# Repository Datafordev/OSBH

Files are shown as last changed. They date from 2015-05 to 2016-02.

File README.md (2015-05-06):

#Open Source Beehives Project #
#Alpha Sensor Kit #
====================================================

Developed for Open Source Beehives Project
http://opensourcebeehives.net

The master branch for the firmware is being rewritten.
The old Code is saved to the Alpha_Kit_02 branch.

**License**
--------
This application contains several libraries and files.  Check the comments section of the .cpp and .h files for the specific details on the licenses.

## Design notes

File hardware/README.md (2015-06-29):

#Open Source Beehives Project #
#Alpha Sensor Kit #
====================================================

Developed for Open Source Beehives Project
http://opensourcebeehives.net

**Hardware AlphaKit V.04**

We designed a shield for the Particle Core/Photon where you can attach following sensors:

- 2x Temp DS18B20
- 2x Temp and Humidity DHT22
- 2x Audio sensor (like audio breakout from SparkFun - more details in audio_sensor)
- 1x Weight sensor

There's also an micro SD Card Slot and a RTC Clock Device installed to be able to work in offline areas.

You'll find a Bill of materials list in bom.ods

**Important for producing the PCB**
It's a doublesided PCB so you need to make sure that pins and vias are through contacted!

**License**
--------
GPL

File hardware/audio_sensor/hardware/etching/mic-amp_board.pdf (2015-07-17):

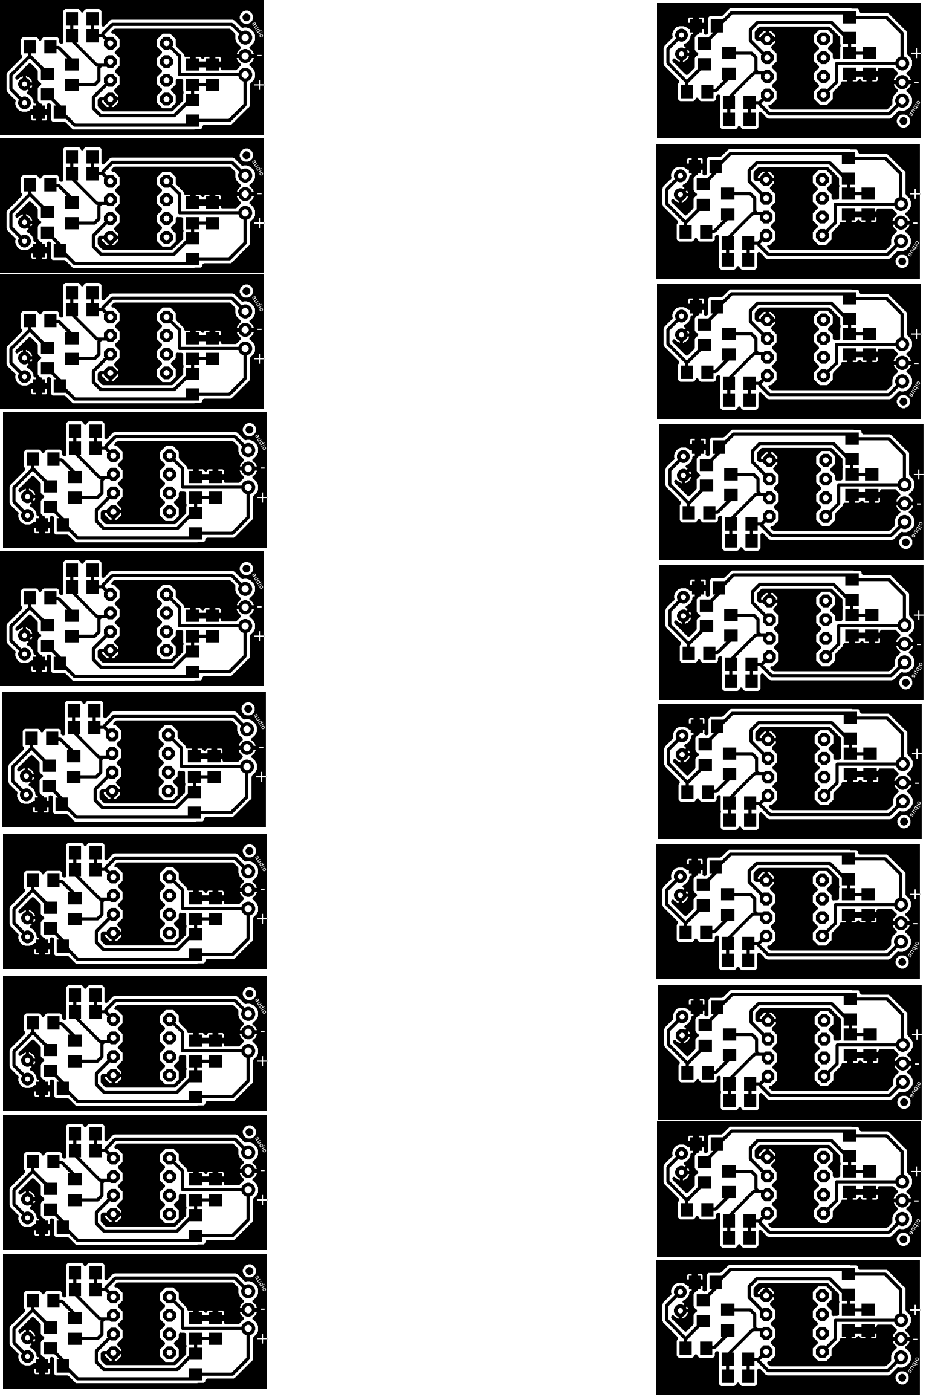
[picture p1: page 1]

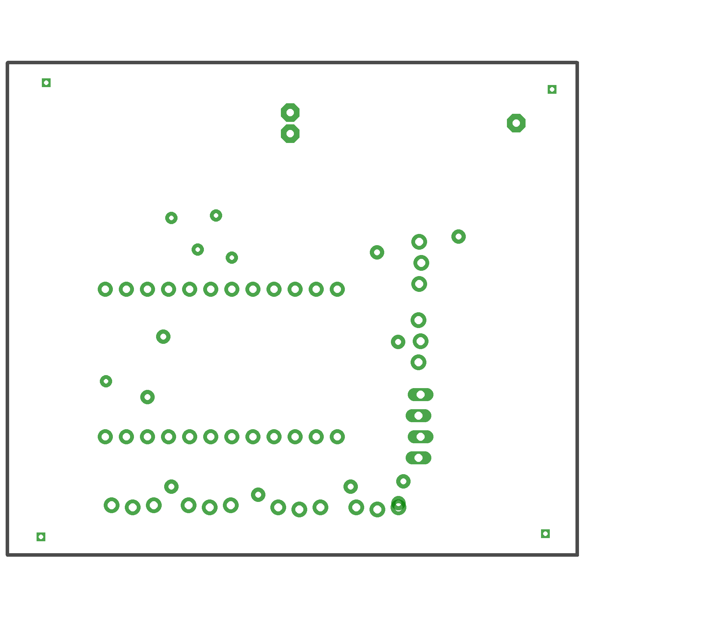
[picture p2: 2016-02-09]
hardware/etching/dimension.png

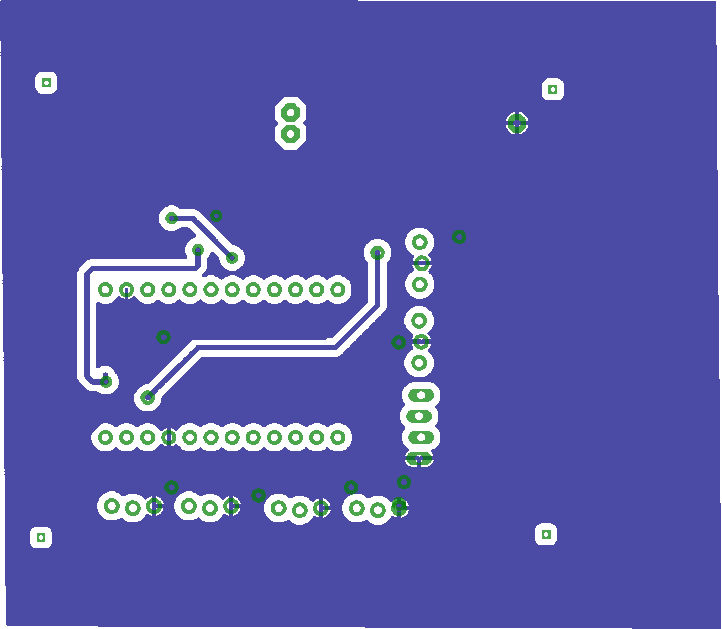
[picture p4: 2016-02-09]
hardware/etching/bottom.png

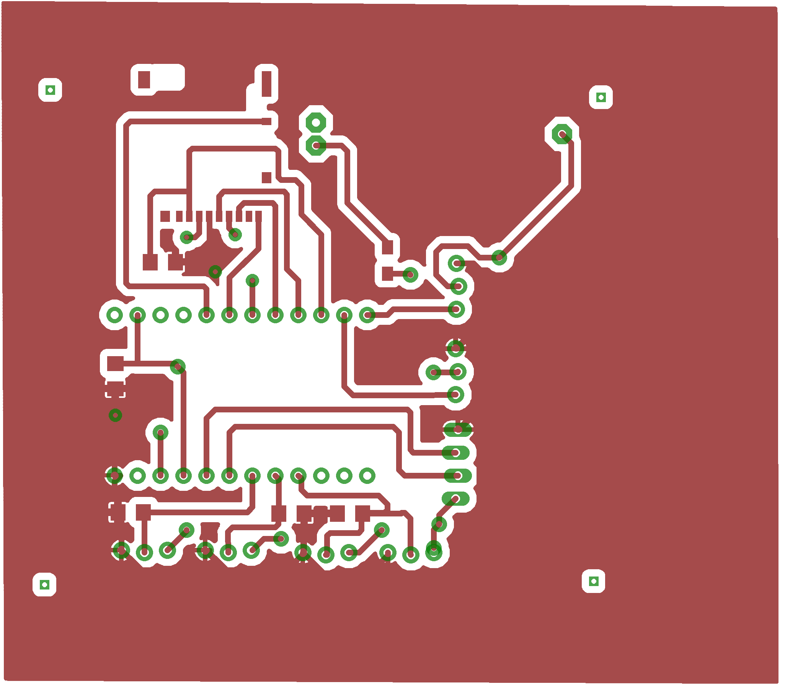
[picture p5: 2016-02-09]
hardware/etching/top.png

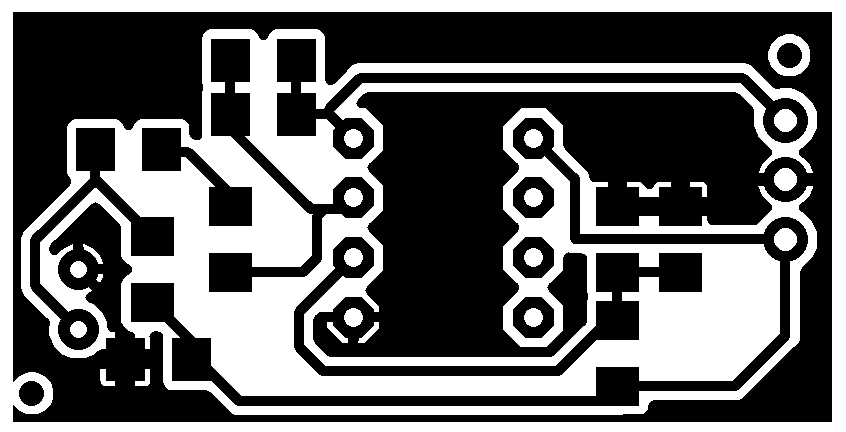
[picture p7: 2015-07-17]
hardware/audio_sensor/hardware/etching/mic-amp_board.png

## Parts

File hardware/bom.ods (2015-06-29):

ID | Type | Designator PCB | Description | Qty
Base Board
1 | Resistor | R5,R6,R7 | 0 Ohm Resistor SMD 1206 | 3
2 | Resistor | R4 | 10kOhm SMD 1206 | 1
3 | Resistor | R1,R2 | 1kOhm SMD 1206 | 2
4 | Resistor | R3 | 4,7kOhm SMD 1206 | 1
5 | Capacitor | C1 | 0.1uF Cap SMD 1206 (not sure yet) | 1
6 | SD Slot | MICROSD-HIROSE | DM3AT-SF-PEJM5 | 1
7 | Male Pins | Audio,Audio1,ADC,DHT03,DHT03_ext,DS18B20,DS18B20ext, | Male pin headers 6x3 + 4 Pin Spacing: 0.1" | 22
8 | Female Pins | JP1,JP2 | Female Headers 2x12 Pin Spacing: 0.1" | 24
9 | Spark Core |  |  | 1
10 | Battery Holder | HU-2032-LF
11 | Real Time Clock | ds1340
 |  |  |  |  | 30,00
Audio Board
10 | Microphone | M1 | MIC-9.7MM Sparkfun | 1
11 | Op-Amp | LM358 or similar | LM358 Op-Amp | 1
12 | Resistor | R1 | 2,2 Kohm Resistor | 1
13 | Capacitor | C1 | 22uF Capacitor SMD 1206 | 1
14 | Resistor | R2,R3,R4 | 10kOhm SMD 1206 | 3
15 | Capacitor | C2 | 1uF Capacitor SMD 1206 | 1
16 | Capacitor | C3 | 100pF Capacitor SMD 1206 | 1
17 | Capacitor | C4 | 0.1uF Cap SMD 1206 | 1
18 | Resistor | R5 | 1MOhm Resistor 1206 | 1
 |  |  |  |  | 5,00
Sensors
19 | Temp-Sensor |  | DS18B20 | 2 | 5
20 | HUMSensor |  | DHT22 Sensor | 2 | 8,00
21 | Weight |  | H30A Bosche Load Cell | 1 | 40
22 | ADC |  | Hx711 AD-Converter | 1 | 3
Connections
22 | Cables 3 wire |  | Cables 3 wires: Audio + 2x Hum (+Temp) ~ 50cm | 3 | 1
23 | Cables 4 wire |  | Cables 4 wire: ADC to Base Board | 1 | 0,5
Scales Construction
???
 |  |  |  |  | 92,5

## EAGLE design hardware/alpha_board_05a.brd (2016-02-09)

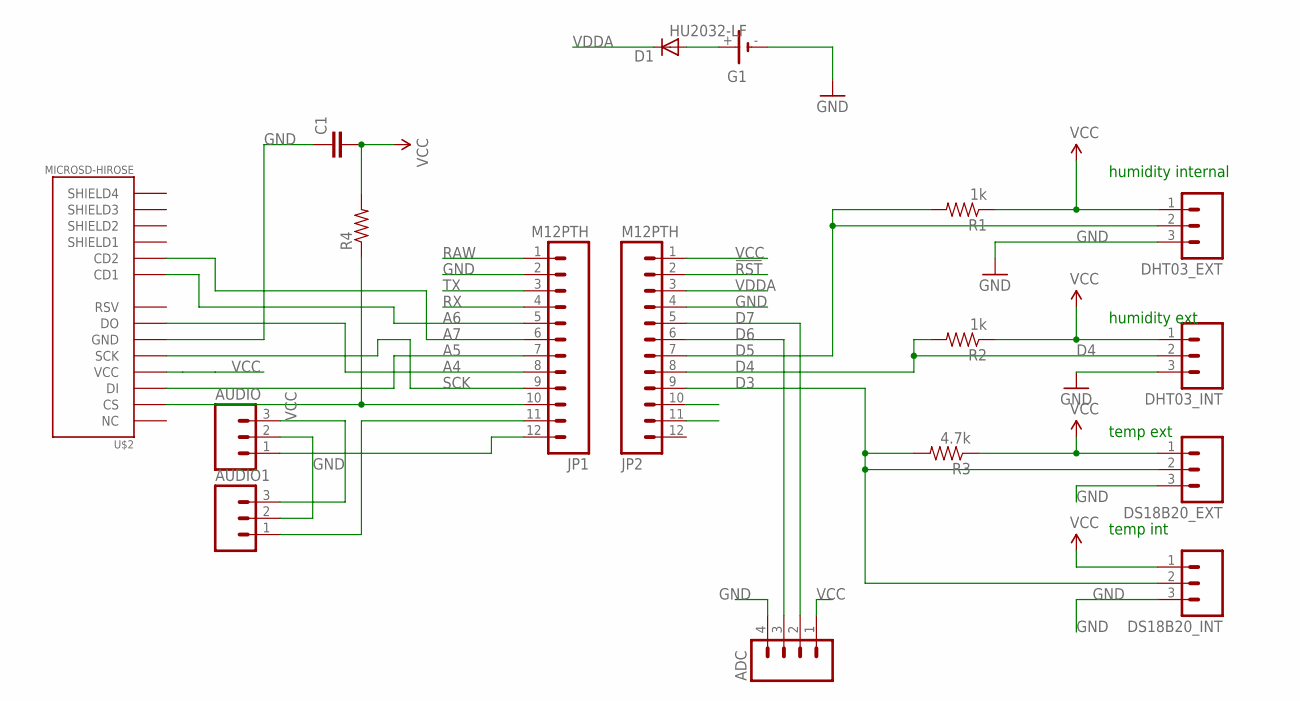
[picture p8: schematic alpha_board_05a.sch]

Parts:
ADC: M04LOCK_LONGPADS; 1X04_LOCK_LONGPADS
AUDIO, AUDIO1: M03LOCK; 1X03_LOCK
C1: CAP1206; 1206
D1: DIODE-SOD323-W; SOD323-W
DHT03_EXT, DHT03_INT: M03LOCK; 1X03_LOCK
DS18B20_EXT, DS18B20_INT: M03LOCK; 1X03_LOCK
G1: HU2032-LF
JP1, JP2: M12PTH; 1X12-SMALL-PADS
R1, R2: 1k; 1206
R3: 4.7k; 1206
R4: RESISTOR1206; 1206
U$2: MICROSD-HIROSE; MICROSD_HOLDER-HIROSE-DM3AT

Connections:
!RST: JP2.2
A4: JP1.8, U$2.DAT0 (DO)
A5: JP1.7, U$2.CMD (DI)
A6: JP1.5, U$2.CD1
A7: JP1.6, U$2.CD2
D3: DS18B20_EXT.2, DS18B20_INT.2, JP2.9, R3.2
D4: DHT03_INT.2, JP2.8, R2.2
D5: DHT03_EXT.2, JP2.7, R1.2
D6: ADC.3, JP2.6
D7: ADC.2, JP2.5
GND: ADC.4, AUDIO.2, AUDIO1.2, C1.1, DHT03_EXT.3, DHT03_INT.3, DS18B20_EXT.3, DS18B20_INT.3, G1.-, JP1.2, JP2.4, U$2.VSS (GND)
unnamed: JP1.10, R4.1, U$2.DAT3 (CS)
unnamed: AUDIO.1, JP1.12
unnamed: D1.A, G1.+
unnamed: AUDIO1.1, JP1.11
RAW: JP1.1
RX: JP1.4
SCK: JP1.9, U$2.CLK (SCK)
TX: JP1.3
VCC: ADC.1, AUDIO.3, AUDIO1.3, C1.2, DHT03_EXT.1, DHT03_INT.1, DS18B20_EXT.1, DS18B20_INT.1, JP2.1, R1.1, R2.1, R3.1, R4.2, U$2.VDD (VCC)
VDDA: D1.C, JP2.3

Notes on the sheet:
humidity internal
temp int
temp ext
humidity ext

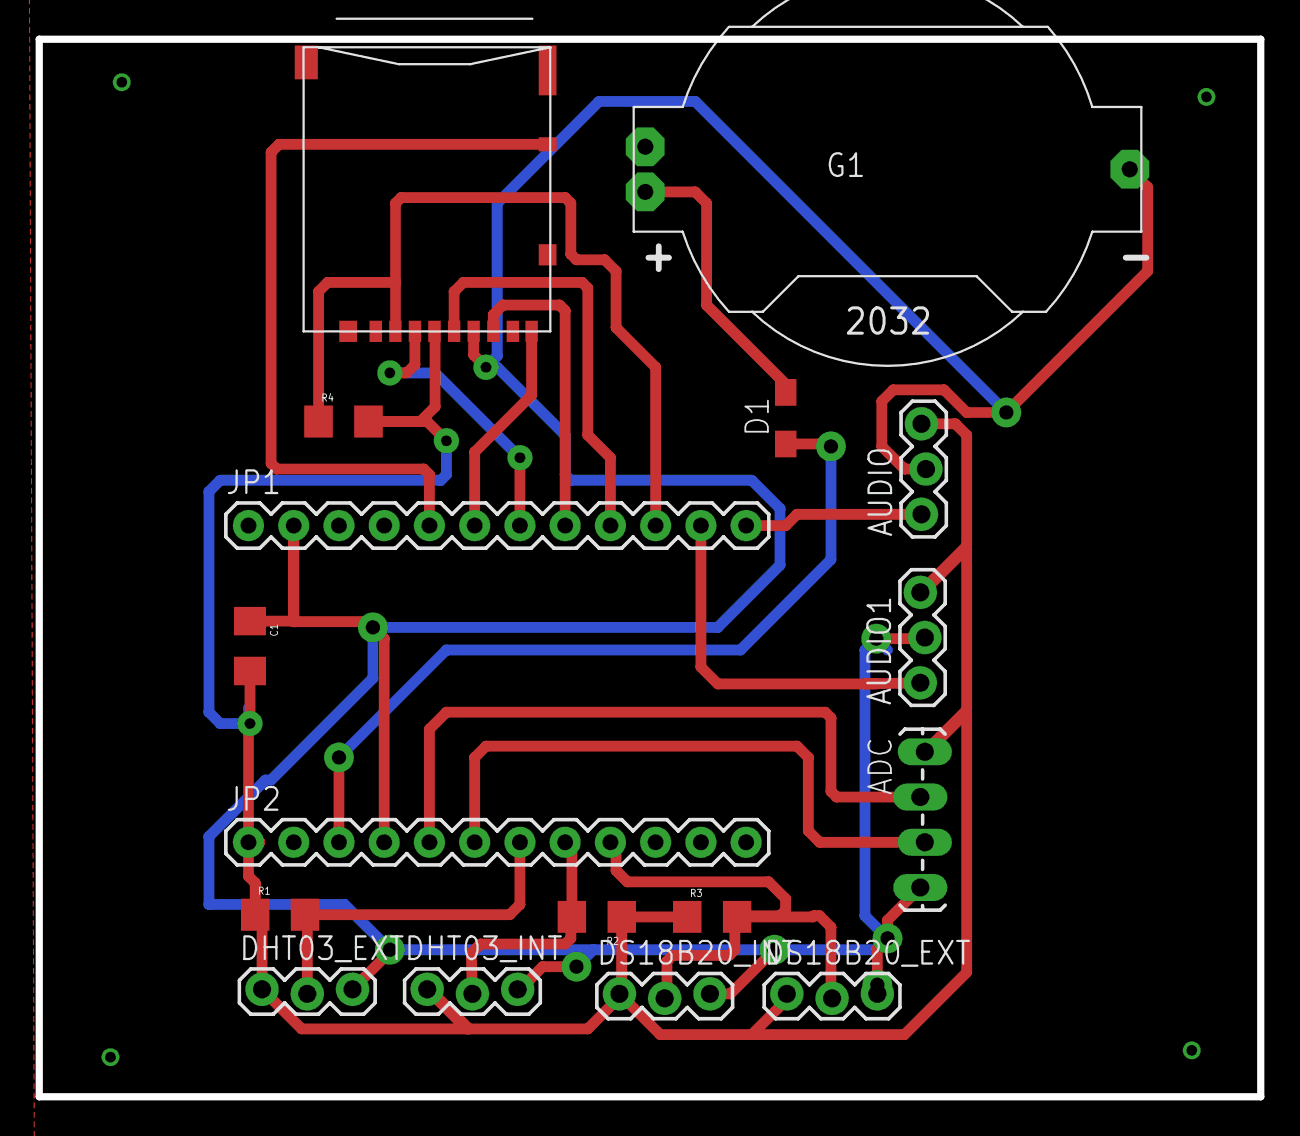
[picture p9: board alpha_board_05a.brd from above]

Board: 2 copper layers, 68.6 x 59.4 mm, 17 parts (0 on the bottom side), 17 nets.

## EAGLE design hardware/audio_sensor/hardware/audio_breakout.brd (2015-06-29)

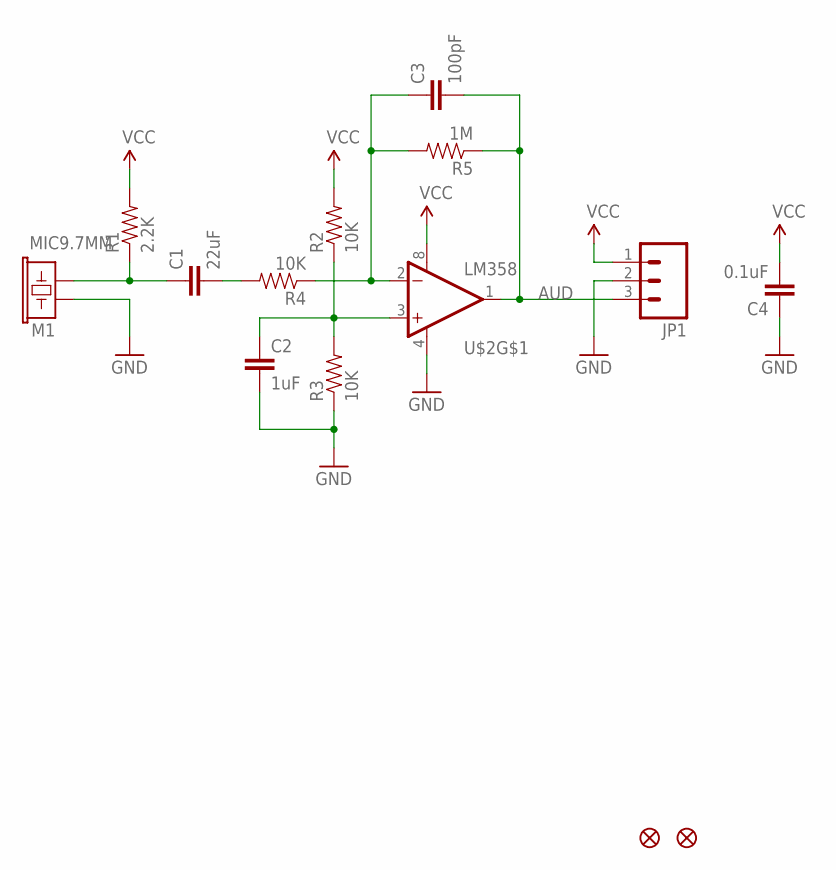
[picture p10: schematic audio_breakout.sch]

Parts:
C1: 22uF; 1206
C2: 1uF; 1206
C3: 100pF; 1206
C4: 0.1uF; 1206
JP1: M03PTH; 1X03
JP2, JP3: FIDUCIAL1X2; FIDUCIAL-1X2
M1: MIC9.7MM; MIC-9.7MM
R1: 2.2K; 1206
R2, R3, R4: 10K; 1206
R5: 1M; 1206
U$2: LM358; DIP08

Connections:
AUD: C3.2, JP1.3, R5.1, U$2.1 (OUT)
GND: C2.2, C4.1, JP1.2, M1.2, R3.1, U$2.4 (V-)
unnamed: C1.1, M1.1, R1.1
unnamed: C3.1, R4.1, R5.2, U$2.2 (-IN)
unnamed: C1.2, R4.2
unnamed: C2.1, R2.1, R3.2, U$2.3 (+IN)
VCC: C4.2, JP1.1, R1.2, R2.2, U$2.8 (V+)

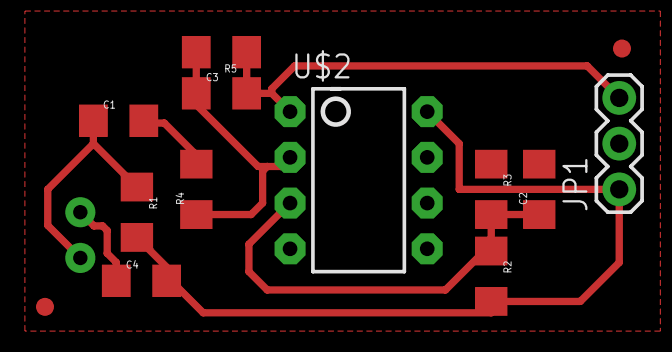
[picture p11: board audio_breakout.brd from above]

Board: 2 copper layers, 14 parts (1 on the bottom side), 7 nets.

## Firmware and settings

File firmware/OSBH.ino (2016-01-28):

#include "config.h"
#include "util.h"
#include "Sensor_Array.h"
#include "sd-card-library.h"
#include "audio.h"
#include "MQTT.h"

using namespace OSBH;

// disable wifi on boot
SYSTEM_MODE(SEMI_AUTOMATIC);

// global sensor array
Sensor_Array sensors(ONE_WIRE_PIN, DHT_PIN1, DHT_PIN2, DHT_TYPE);

// whether there's an SD card present in the socket
enum SD_State { SD_REMOVED, SD_READY, SD_UNPREPARED };
SD_State sd_state = SD_REMOVED;

// buffer for reading/writing strings. Using the spark/wiring String class
// would be more convenient, but risks memory fragmentation.
static const int IO_BUFFER_LEN = 36;
char io_buffer[IO_BUFFER_LEN];

/**************************************************************************/
/*
        MQTT Communication
 */
/**************************************************************************/


void callback(char* topic, byte* payload, unsigned int length);

/**
 * if want to use IP address,
 * byte server[] = { XXX,XXX,XXX,XXX };
 * MQTT client(server, 1883, callback);
 * want to use domain name,
 * MQTT client("www.sample.com", 1883, callback);
 **/
MQTT client( MQTTSERVER , MQTTSERVERPORT , callback);

// recieve message
void callback(char* topic, byte* payload, unsigned int length) {
    char p[length + 1];
    memcpy(p, payload, length);
    p[length] = NULL;
    String message(p);

    if (message.equals("RED"))    
        RGB.color(255, 0, 0);
    else if (message.equals("GREEN"))    
        RGB.color(0, 255, 0);
    else if (message.equals("BLUE"))    
        RGB.color(0, 0, 255);
    else    
        RGB.color(255, 255, 255);
    delay(1000);
}





/**************************************************************************/
/*
        Utility functions
 */
/**************************************************************************/

// writes the contents of io_buffer to all the currently active output destinations.
// last_entry indicates whether the contents of the buffer fall at the end of a
// line of sensor data.
void write(bool last_entry = false)
{
    // double-check that buffer is null-terminated
    io_buffer[IO_BUFFER_LEN-1] = '\0';

    // prep for writing as CSV
    append_suffix(io_buffer, IO_BUFFER_LEN, (last_entry ? LINE_END : DELIMITER));

    // save data to SD card, if it's ready
    if (sd_state == SD_READY && !write_to_sd(SD, io_buffer, LOGFILE_NAME)) {
        DEBUG_PRINTLN("could not write to SD card");
        sd_state = SD_UNPREPARED; // attempt to re-initialize later
    } 

    // print to debug output
    DEBUG_PRINT(io_buffer);
}

// output audio data to seperate audio file
void audio_write()
{
	get_timestamp(io_buffer, IO_BUFFER_LEN, GMT_OFFSET);
	// null-termination
	io_buffer[IO_BUFFER_LEN-1] = '\0';
	// append end-delimiter
	append_suffix(io_buffer, IO_BUFFER_LEN, LINE_END );
	// write to SD
	if (sd_state == SD_READY && !write_to_sd(SD, io_buffer, LOGFILE_NAME_AUDIO)) {
        DEBUG_PRINTLN("failed to write to SD card");
        sd_state = SD_UNPREPARED; // attempt to re-initialize later
    }
	updateFFT();
	for(int i=0; i < FFT_SIZE/2+2; i++) {   
        csv_audio_output(io_buffer, IO_BUFFER_LEN, i);
         
			// double-check that buffer is null-terminated
			io_buffer[IO_BUFFER_LEN-1] = '\0';
			// save data to SD card, if it's attached
			if (sd_state == SD_READY && !write_to_sd(SD, io_buffer, LOGFILE_NAME_AUDIO)) {
				DEBUG_PRINTLN("failed to write to SD card");
				sd_state = SD_UNPREPARED; // attempt to re-initialize later
			}
			// print to debug output
			  DEBUG_PRINT(io_buffer);
	}
}

// interrupt handler for SD card
void update_sd_state()
{
    if (!digitalRead(SD_CD_PIN_IN)) {
        // card is absent
        sd_state = SD_REMOVED;
    } else if (sd_state == SD_REMOVED) {
        // card is present, but was previously removed, so requires initialization
        sd_state = SD_UNPREPARED;
    }
}

/**************************************************************************/
/*
        Function:  setup
 */
/**************************************************************************/
void setup() 
{
    Serial.begin(9600);
    DEBUG_PRINTLN("starting setup...");

   // attempt to connect to wifi
    if (!init_wifi()) {
        DEBUG_PRINTLN("could not establish wifi connection");
    }
    else
    {
		 // connect to the mqtt server
			client.connect(MQTTID, MQTTUSER, MQTTPSW);
			if(!client.isConnected()) {
				 DEBUG_PRINTLN("could not connect to mqtt server");
			}
			else
			{
				DEBUG_PRINTLN("connected to:");
				DEBUG_PRINTLN(MQTTSERVER);
			}
	}

    // initialize sensors
    sensors.begin();

    // reserve memory for FFT (audio analysis)
    FFTinit();

    // attach interrupt on SD card-detect pin to catch inserts/removes
    pinMode(SD_CD_PIN_OUT, OUTPUT); // output signal
    digitalWrite(SD_CD_PIN_OUT, HIGH); // send high
    pinMode(SD_CD_PIN_IN, INPUT_PULLDOWN); // usual input = 0 == card not attached
    attachInterrupt(SD_CD_PIN_IN, update_sd_state, CHANGE); // interrupt function which waits for pin input Change
    update_sd_state(); // set initial state

    // write header for timestamp column
    strncpy(io_buffer, "Timestamp", IO_BUFFER_LEN);
    write();

    // write sensor names/IDs as CSV headers
    for (uint8_t i = 0; i < sensors.count(); ++i) {
        sensors.getSensorString(i, io_buffer, IO_BUFFER_LEN);
        write(i == sensors.count() - 1);
    }

    DEBUG_PRINTLN("setup complete");
}

/**************************************************************************/
/*
        Function:  loop
 */
/**************************************************************************/
void loop() 
{
    // timing variables
    static uint32_t next_sync;
    static uint32_t next_read;
    const uint32_t now = millis();

    // make sure our read interval respects our minimum sensor delays
    static const uint32_t read_interval = max(IDEAL_READ_INTERVAL, sensors.minDelay());

	
	
    // time synchronization
    if (now > next_sync) {
        DEBUG_PRINTLN("syncing time...");
        sync_time();
        next_sync = now + ONE_DAY_MILLIS;
    }


    // initialize SD card if necessary
    if (sd_state == SD_UNPREPARED) {
        SD.begin();
        sd_state = SD_READY;
    }
    
    // read and report sensor data
    if (now > next_read) 
    {
		
        DEBUG_PRINTLN("reading...");

        // write timestamp
        get_timestamp(io_buffer, IO_BUFFER_LEN, GMT_OFFSET);
        write();
		
		
        // get sensor readings
        for (uint8_t i = 0; i < sensors.count(); ++i) {
            sensors.getEventString(i, io_buffer, IO_BUFFER_LEN);
            
            //mqtt write
            char tempstr[30] = "";
            strcpy(tempstr, MQTTBASETOPIC);
            strcat(tempstr, mqtttopics[i]); 
            if(client.isConnected()){
            client.publish("ronjac/feeds/Bienensensor","20000.00;");
            DEBUG_PRINTLN(tempstr);
            DEBUG_PRINTLN("jemand da?");
			}
			else //try again if not connected
			{
				client.connect(MQTTID, MQTTUSER, MQTTPSW);
				if(client.isConnected()){
				client.publish("nn/feeds/Temp1",io_buffer);
				
				}
			}
            
            //end mqtt write
            
            write(i == sensors.count() - 1);

        }
        

        //perform audio analysis
       //updateFFT();
       //audio_write();
		updateFFT();
		char tempstr[30] = "";
		strcpy(tempstr, MQTTBASETOPIC);
		strcat(tempstr, MQTTAUDIOTOPIC);
		DEBUG_PRINTLN(tempstr);
		for(int i=0; i < FFT_SIZE/2+2; i++) {   
			mqtt_audio_output(io_buffer, IO_BUFFER_LEN, i);
			client.publish(tempstr,io_buffer);
			delay(500);
		}
		

		
        next_read = now + read_interval; 
		
       
    }
    
        if (Spark.connected()) Spark.process();
		Serial.println(Time.timeStr());
		delay(1000);
}

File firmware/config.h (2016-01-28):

#ifndef __CONFIG_H__
#define __CONFIG_H__

#include "application.h"


// 1: debug printing, 0: no debug printing
#define OSBH_DEBUG 1

#if OSBH_DEBUG
    #define DEBUG_PRINT(...) Serial.print(__VA_ARGS__);
    #define DEBUG_PRINTLN(...) Serial.println(__VA_ARGS__);
#else
    #define DEBUG_PRINT(...) do {} while (0)
    #define DEBUG_PRINTLN(...) do {} while (0)
#endif

/* Pin and sensor definitions */
#define ONE_WIRE_PIN   3
#define DHT_PIN1       4         // Pin for internal DHT sensor.
#define DHT_PIN2       5         // Pin for external DHT sensor.
#define DHT_TYPE       DHT22     // DHT 22 (AM2302)
#define SD_CD_PIN_IN   A6
#define SD_CD_PIN_OUT  A7

/* Audio analysis parameters */
int MICROPHONE = 10;        // A0 on spark Core/Photon
int FFT_SIZE = 128;         //FFT Bucket Size (32,64,128,256 - higher means more frequency resolution)
int SAMPLEDELAY = 600;      //Delay for sampling in microseconds f = 1/t*10^6

/* Configuration variables */
#define IDEAL_READ_INTERVAL 5000 // may be adjusted upward to match sensors' min_delays

/* Output variables */
#define LOGFILE_NAME "osbh.csv"
#define LOGFILE_NAME_AUDIO "audio.csv"
#define DELIMITER ","
#define LINE_END "\n"
#define GMT_OFFSET 1

/* Database Connection */
#define MQTTSERVER "io.adafruit.com"
#define MQTTSERVERPORT 1883
#define MQTTID "sparkclient"
#define MQTTUSER "ronjac"
#define MQTTPSW "92227a87656a7029f7758fc1283abe79320a8673"

/* MQTT Topics */
char* MQTTBASETOPIC = "ronjac/feeds";
char* MQTTAUDIOTOPIC = "/audio";
char* mqtttopics[] = {"/DHT1temp", "/DHT1hum", "/DHT2temp", "/DHT2hum", "/Temp1", "/Temp2"};


#endif

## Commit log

2015-05-10 add DHT and dallas sensor libs; move libs to subdirectory; change includes
2015-05-10 add minimal sketch (no sensors yet)
2015-05-11 deleted Piettech in DSX and few changes for new Adafruit Sensor
2015-05-22 re-add DHT22 sensors as well; respect sensors' minimum read intervals
2015-05-22 wrap sensors in a sensor_array class, reorganize files OSBH.cpp and OSBH.ino were causing linker name conflicts
2015-06-06 use char arrays instead of String for timestamp and output to avoid memory fragmentation
    [OSBH.ino, config.h]
2015-06-06 add TEMP/HUM suffix to DHT* sensor names
2015-06-29 hardware added
    [alpha_board.brd, alpha_board.sch, audio_breakout.brd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]
2015-06-29 bom added
    [bom.ods]
2015-07-06 make output format more configurable, fix warning in DHT_U library
    [OSBH.ino, config.h]
2015-07-06 use SD CD pin to handle card removal/re-insertion
2015-07-17 hardware update, new RTC chip, smaller footprint
    [alpha_board.brd, alpha_board.sch]
2015-11-19 update firmware to track changes in Particle firmware
2016-01-28 04 update, SD pin detect, audio output, mqtt database connection, RTC
2016-01-28 new PCB design without external RTC, thanks Angel M!
    [alpha_board.brd, alpha_board.sch]
2016-02-09 few bug changes
    [alpha_board_05a.brd, alpha_board_05a.sch]

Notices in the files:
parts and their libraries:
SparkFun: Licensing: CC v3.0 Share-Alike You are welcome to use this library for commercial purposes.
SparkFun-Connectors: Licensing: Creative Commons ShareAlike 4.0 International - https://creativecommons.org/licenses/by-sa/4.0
